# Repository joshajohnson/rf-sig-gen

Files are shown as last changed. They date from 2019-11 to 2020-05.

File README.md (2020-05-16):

# RF Signal Generator

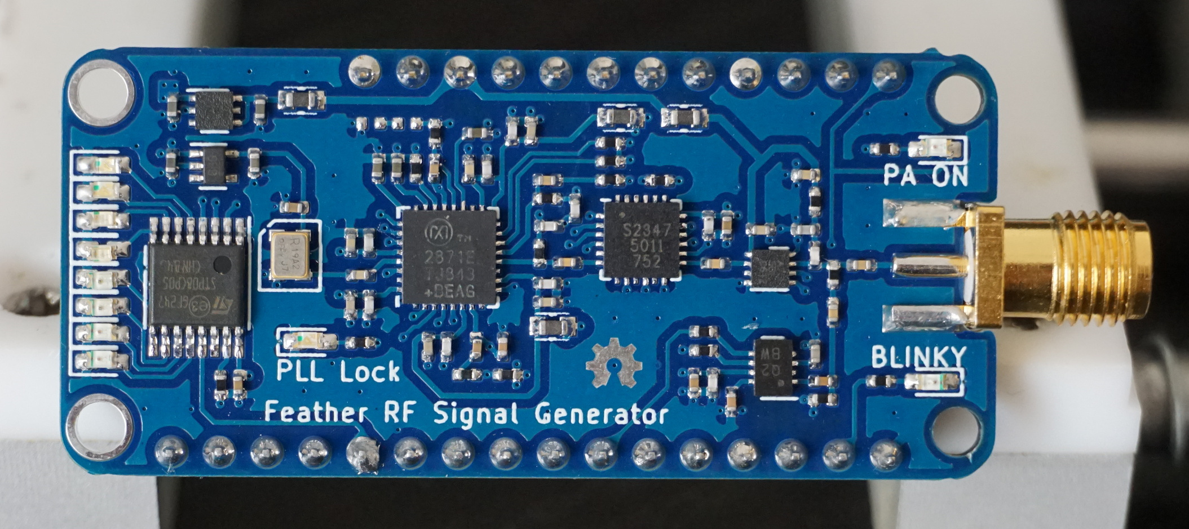
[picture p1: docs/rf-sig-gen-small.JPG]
Signal Generator


## 23.5 - 6000 MHz MAX2871 based RF signal generator in an Adafruit Feather form factor.
- MAX2871 23.5 - 6000 MHz Fractional/Integer-N Synthesizer/VCO
- -35 to +15 dBm output power (-25 to +10 across entire frequency range)
- Output control within 0.5 dB, with closed loop feedback
- GUI allowing easy control, including sweep capabilities
- Adafruit Feather form factor
- Firmware works with my [STM32F103 Feather](https://github.com/joshajohnson/stm32f103-feather)

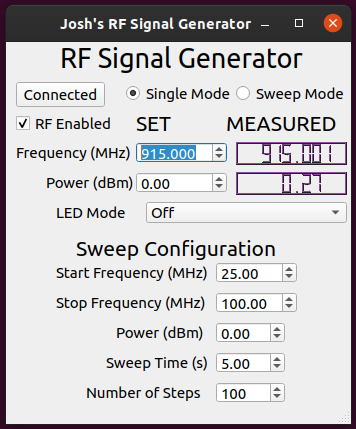
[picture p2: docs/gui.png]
GUI

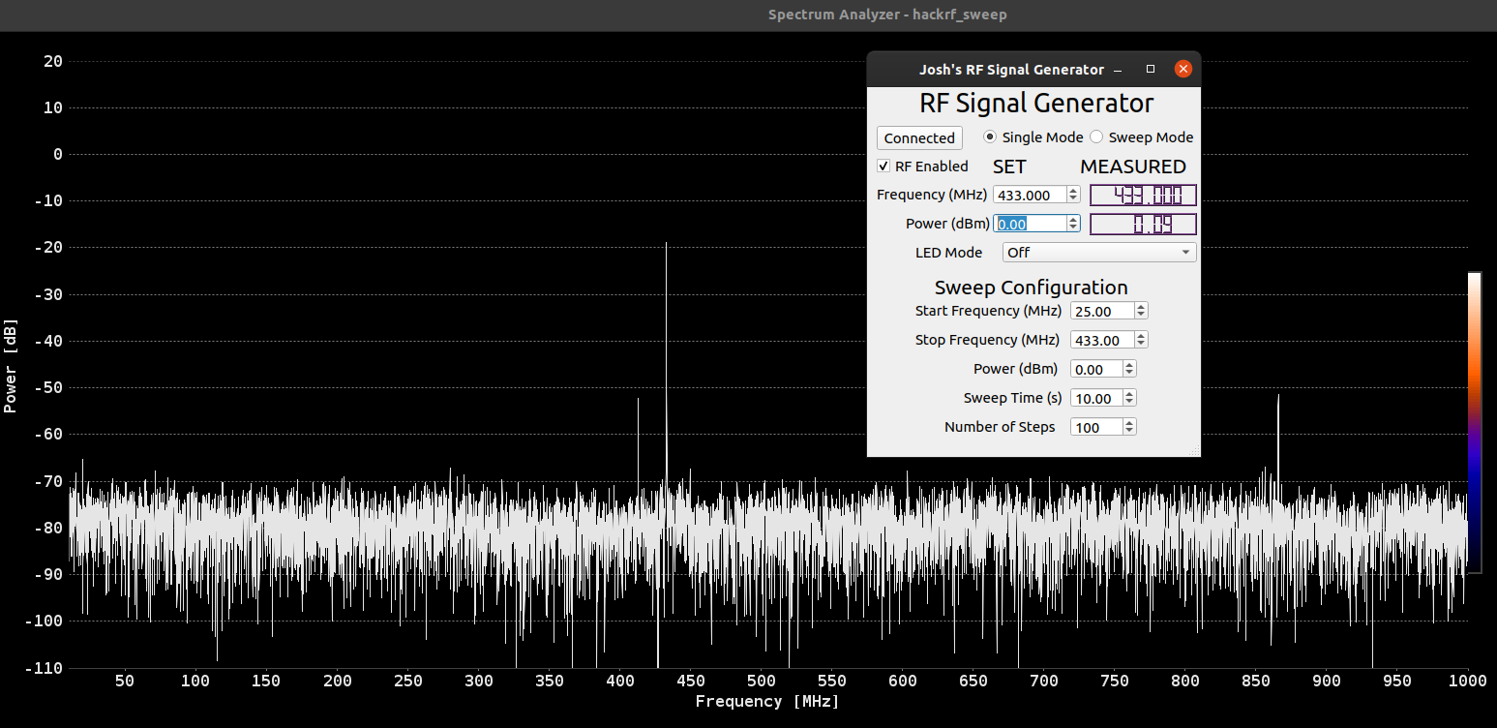
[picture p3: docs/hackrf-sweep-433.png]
GUI with hackrf_sweep spectrum view


### TODO

#### Software
- [ ] Display not updating if time between frequency steps in sweep is too long (greater than UART timeout)
- [ ] Map keyboard to frequency and power adjustment in GUI
- [ ] CLI and GUI modes based on sys.argv **NOTE CLI works but is very finiky wrt command order and updating**
- [ ] Fractional vs Int N selection

#### Firmware
- [ ] Calibrate output power
- [ ] Rewrite with RTOS to ensure a more responsive user experience
- [ ] Add ability to select Frac / Int N PLL settings
- [ ] Dimmable LEDs

#### Hardware
- [ ] Many pin locations incorrect (SPI pins off by one...)
- [ ] LED's back to front, and connected to GND instead of VCC
- [ ] Feather footprint internal pin numbers incorrect

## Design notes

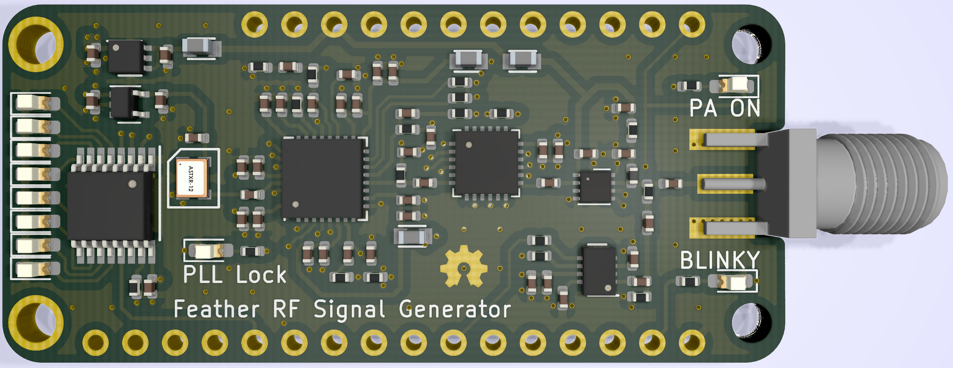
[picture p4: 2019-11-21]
docs/siggen-render.PNG

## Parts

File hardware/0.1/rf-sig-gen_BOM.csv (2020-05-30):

Qty | Reference(s) | Value | Footprint | MPN | DigiKey | LCSC | Manufacturer | DNP | Notes
5 | C1, C23, C27, C41, C43 | 100n | Capacitor_SMD:C_0402_1005Metric
9 | C10, C12, C15, C17, C31, C35, C5, C6, C8 | 10n | Capacitor_SMD:C_0402_1005Metric
10 | C11, C13, C16, C18, C20, C28, C34, C42, C7, C9 | 100p | Capacitor_SMD:C_0402_1005Metric
7 | C14, C19, C2, C21, C25, C3, C4 | 1u | Capacitor_SMD:C_0402_1005Metric
5 | C22, C30, C37, C39, C40 | 1n | Capacitor_SMD:C_0402_1005Metric
1 | C24 | 12n | Capacitor_SMD:C_0402_1005Metric
1 | C26 | DNP | Capacitor_SMD:C_0402_1005Metric
1 | C29 | 820p | Capacitor_SMD:C_0402_1005Metric
1 | C32 | 8p2 | Capacitor_SMD:C_0402_1005Metric
2 | C33, C38 | 47n | Capacitor_SMD:C_0402_1005Metric
1 | C36 | 10p | Capacitor_SMD:C_0402_1005Metric
11 | D1, D10, D11, D2, D3, D4, D5, D6, D7, D8, D9 | LED | LED_SMD:LED_0603_1608Metric_Castellated
4 | FB1, FB2, FB3, FB4 | 600R | josh-passives-smt:Ferrite_Bead_0603
1 | J1 | Feather | josh-connectors:featherwing-short
1 | J2 | SMA | josh-connectors:SMA_EDGE_MOUNT_INSET
1 | L1 | 100n | Inductor_SMD:L_0402_1005Metric
1 | R1 | 5K1 | Resistor_SMD:R_0402_1005Metric
4 | R10, R16, R19, R9 | 1K | Resistor_SMD:R_0402_1005Metric
1 | R11 | 18K | Resistor_SMD:R_0402_1005Metric
1 | R12 | 52R3 | Resistor_SMD:R_0402_1005Metric
3 | R13, R17, R4 | 49R9 | Resistor_SMD:R_0402_1005Metric
1 | R14 | 500R | Resistor_SMD:R_0402_1005Metric
1 | R15 | 1R8 | Resistor_SMD:R_0402_1005Metric
1 | R18 | 10K | Resistor_SMD:R_0402_1005Metric
2 | R2, R3 | 0R0 | Resistor_SMD:R_0402_1005Metric
1 | R20 | 2K2 | Resistor_SMD:R_0402_1005Metric
1 | R5 | 90R9 | Resistor_SMD:R_0402_1005Metric
1 | R6 | 31R1 | Resistor_SMD:R_0402_1005Metric
1 | R7 | DNP | Resistor_SMD:R_0402_1005Metric
1 | R8 | 240R | Resistor_SMD:R_0402_1005Metric
1 | U1 | MAX2871 | josh-dfn-qfn:QFN-32-1EP_5x5mm_Pitch0.5mm_Thermal_Vias
1 | U2 | LP5912 | Package_DFN_QFN:DFN-6-1EP_2x2mm_P0.65mm_EP1x1.6mm
1 | U3 | MIC5366-1.8 | Package_TO_SOT_SMD:SOT-353_SC-70-5
1 | U4 | SKY12347-362LF | Package_DFN_QFN:QFN-24-1EP_4x4mm_P0.5mm_EP2.7x2.7mm_ThermalVias
1 | U5 | TRF37A75 | Package_DFN_QFN:DFN-8-1EP_2x2mm_P0.5mm_EP0.9x1.5mm
1 | U6 | AD8319 | Package_DFN_QFN:DFN-8-1EP_2x3mm_P0.5mm_EP0.61x2.2mm
1 | U7 | STP08CP05 | Package_SO:TSSOP-16_4.4x5mm_P0.65mm
1 | XO1 | ASTXR-12-19.200MHz | josh-oscillators:ASTXR-12

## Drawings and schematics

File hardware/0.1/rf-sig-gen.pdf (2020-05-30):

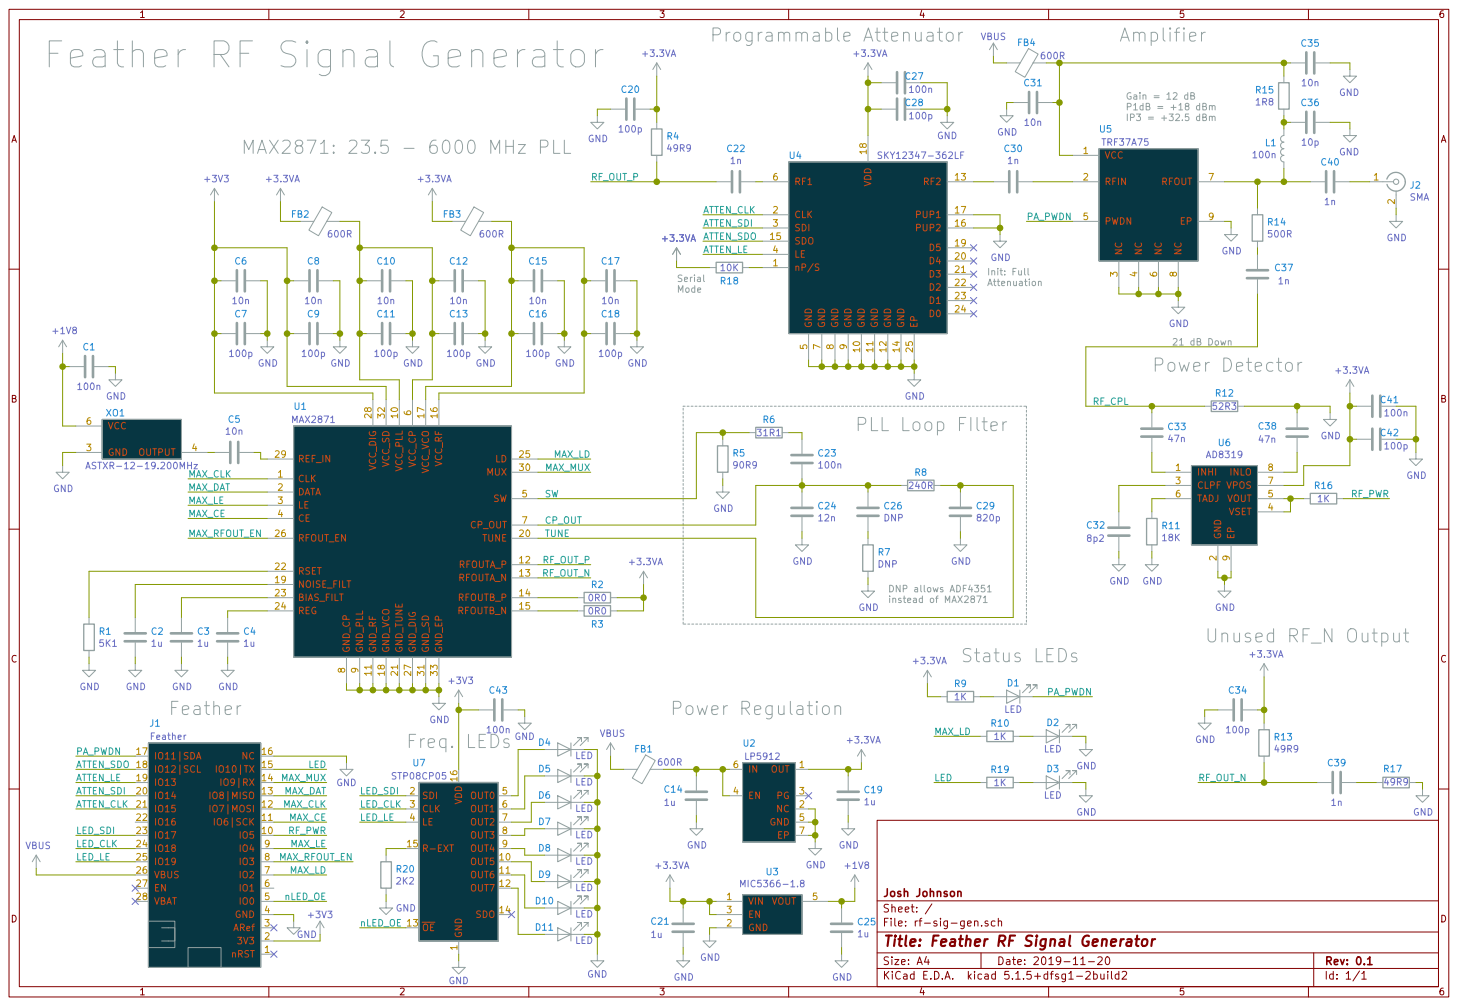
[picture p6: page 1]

9 GND 11 GND 12 RF2 13 GND 14 SDO 15 PUP1 17 D5 19 CLK 2 D4 20 D3 21 D2 22 D1 23 D0 24 SDI 3

Init: Full Attenuation PLL Loop FIlter

21 dB Down Power Detector

2 CLPF 3 VSET 4 VOUT 5 TADJ 6 VPOS 7

File: rf-sig-gen.sch Sheet: / Josh Johnson R3

1 OUT5 10 OUT6 11 OUT7 12 OE 13 SDO 14 R-EXT 15 VDD 16 SDI 2 CLK 3

Id: 1/1 Title: Feather RF Signal Generator

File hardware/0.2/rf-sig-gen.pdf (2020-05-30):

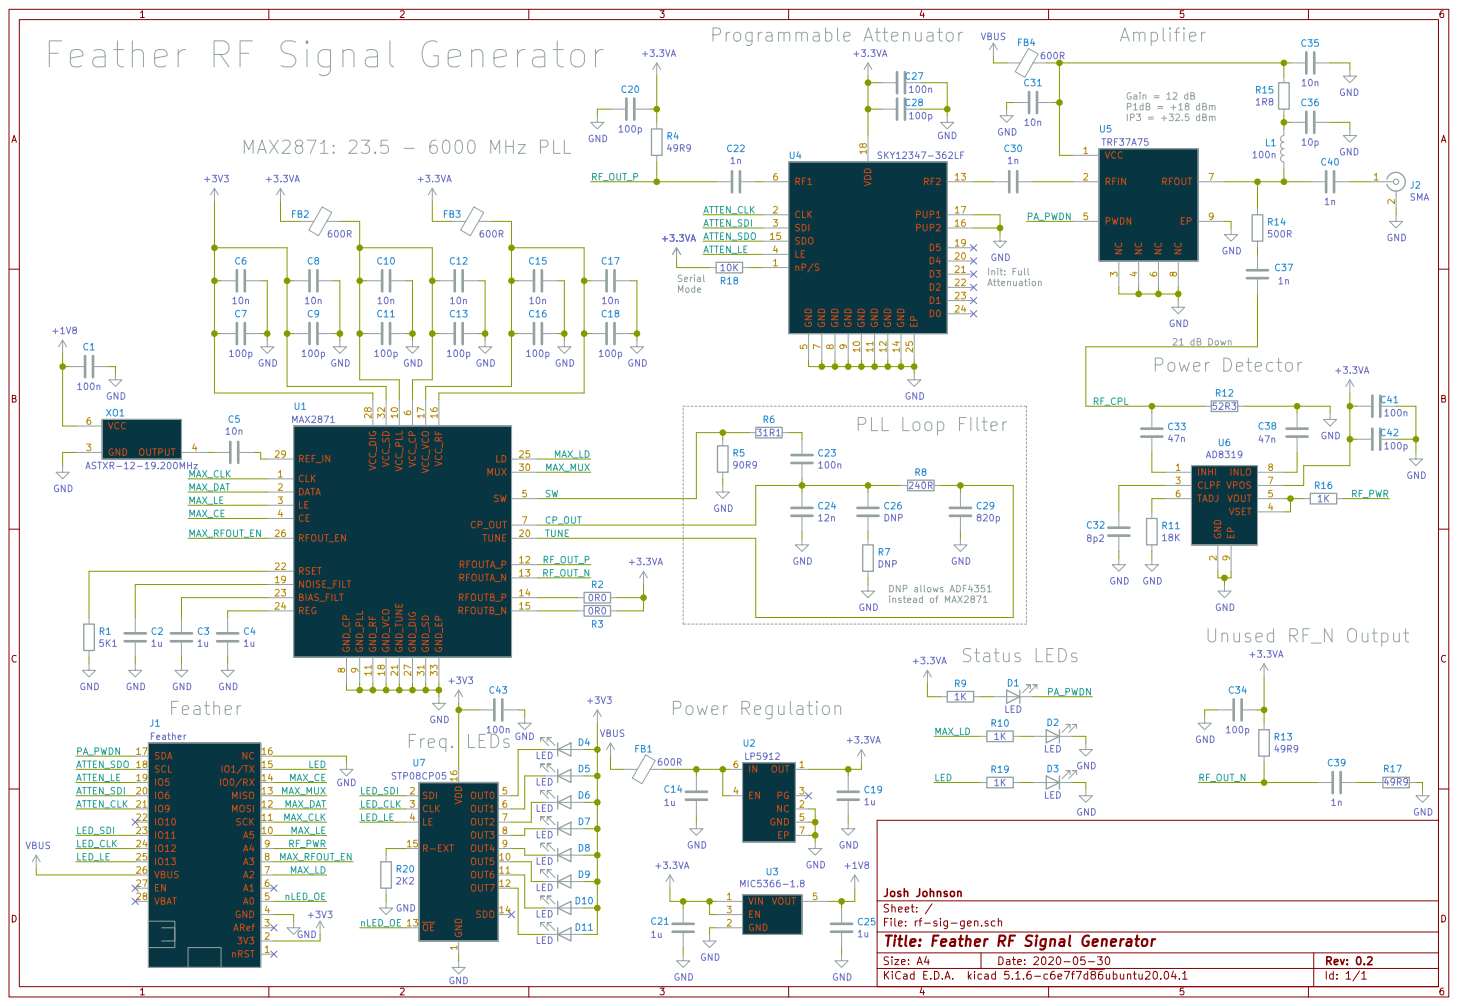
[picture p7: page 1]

21 dB Down Feather RF Signal Generator

Init: Full Attenuation MAX2871: 23.5 - 6000 MHz PLL

9 GND 11 GND 12 RF2 13 GND 14 SDO 15 PUP1 17 D5 19 CLK 2 D4 20 D3 21 D2 22 D1 23 D0 24 SDI 3
100p GND

instead of MAX2871 PLL Loop FIlter

2 CLPF 3 VSET 4 VOUT 5 TADJ 6 VPOS 7

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

Id: 1/1 Title: Feather RF Signal Generator

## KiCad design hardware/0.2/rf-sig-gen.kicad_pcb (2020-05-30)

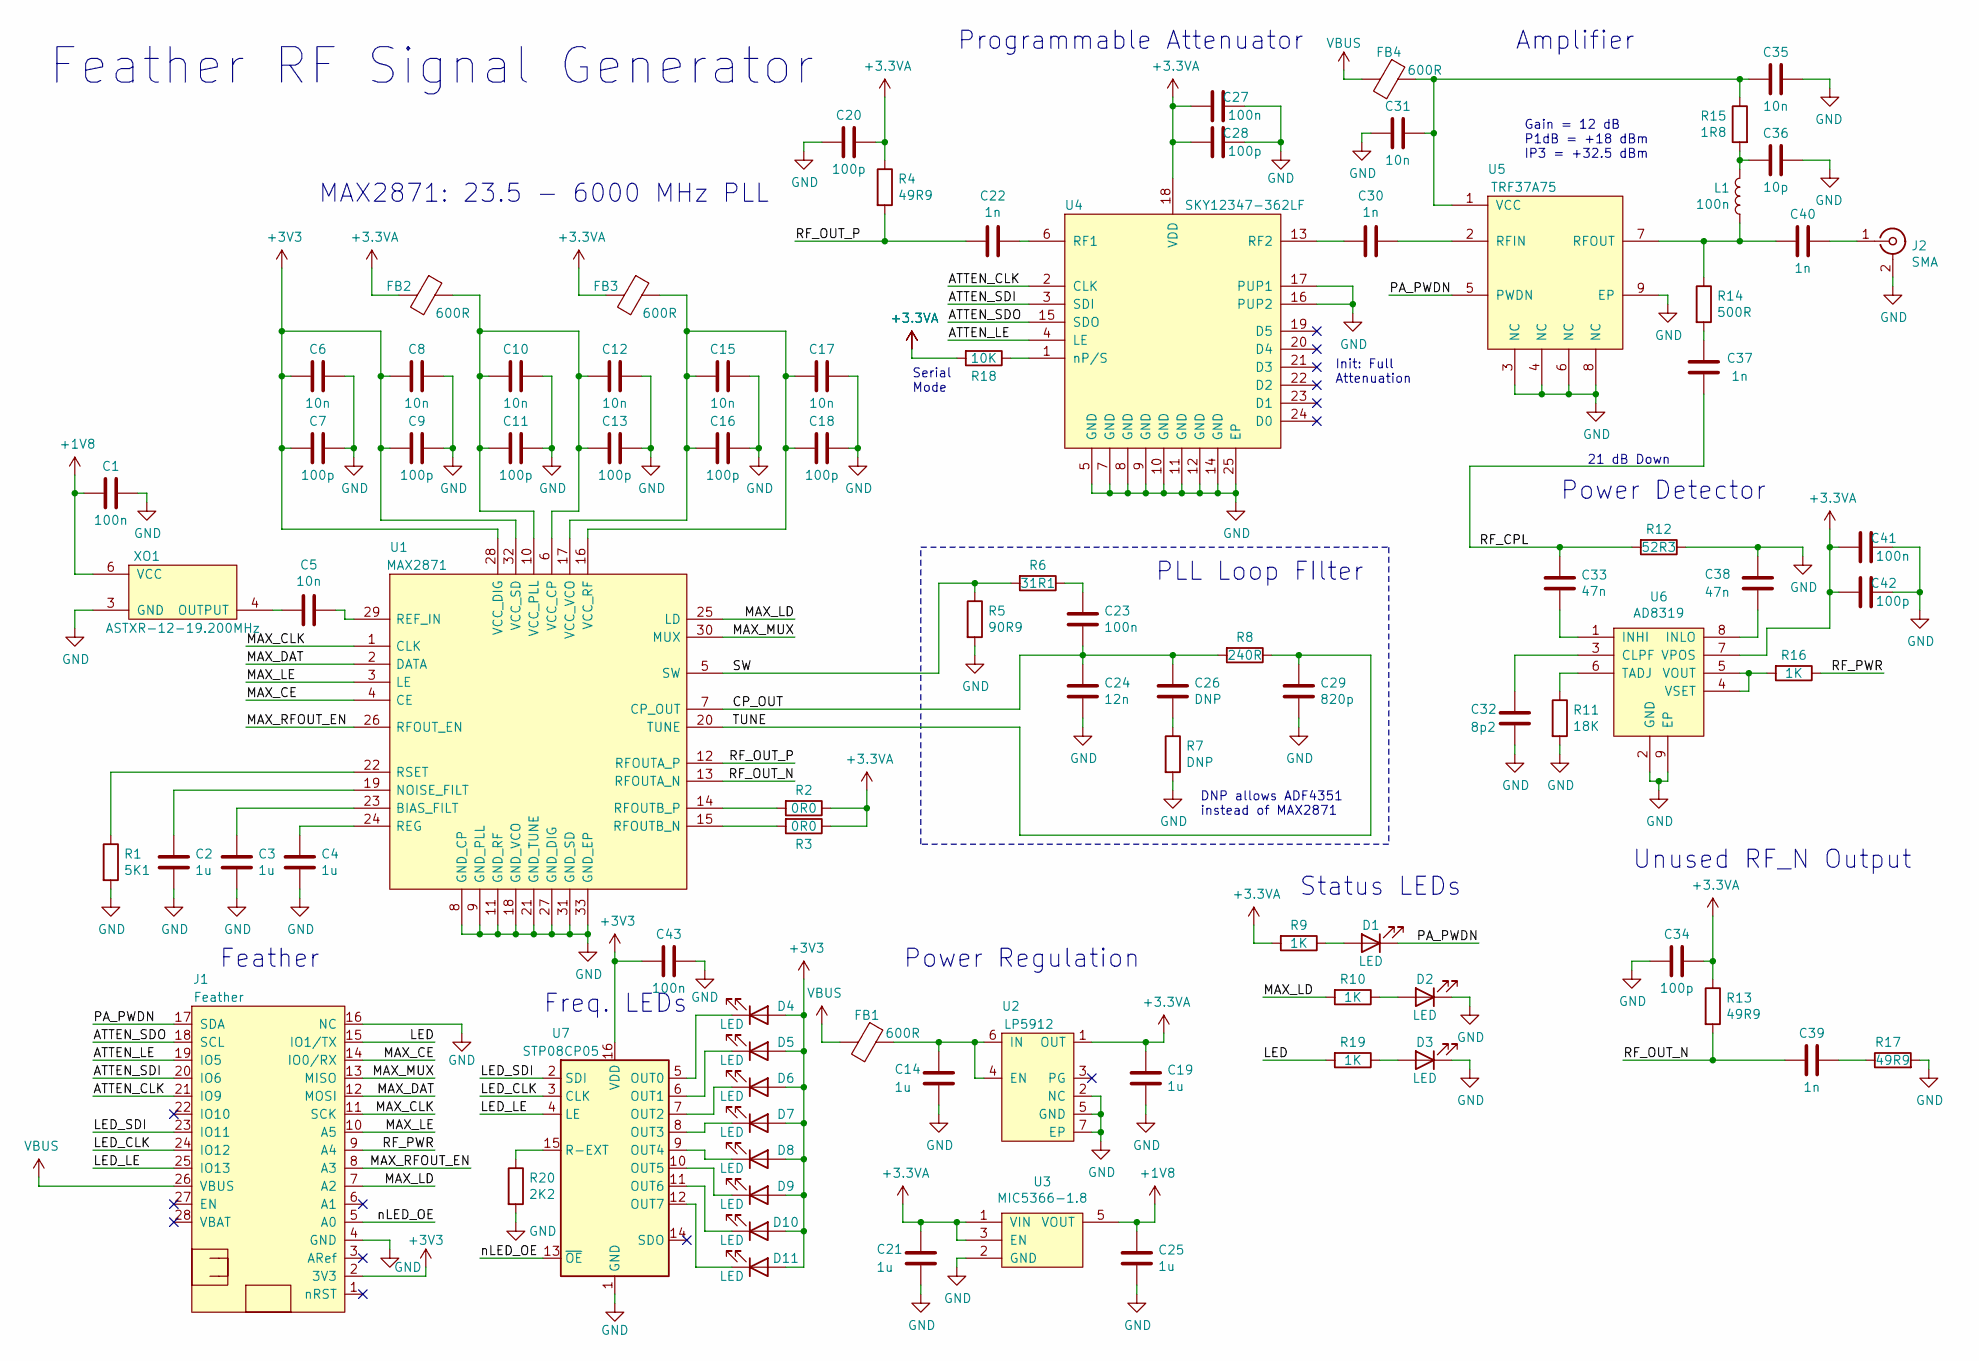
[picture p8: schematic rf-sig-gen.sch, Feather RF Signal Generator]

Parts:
C1, C23, C27, C41, C43: 100n; C_0402_1005Metric
C2, C3, C4, C14, C19, C21, C25: 1u; C_0402_1005Metric
C5, C6, C8, C10, C12, C15, C17, C31, C35: 10n; C_0402_1005Metric
C7, C9, C11, C13, C16, C18, C20, C28, C34, C42: 100p; C_0402_1005Metric
C22, C30, C37, C39, C40: 1n; C_0402_1005Metric
C24: 12n; C_0402_1005Metric
C26: DNP; C_0402_1005Metric
C29: 820p; C_0402_1005Metric
C32: 8p2; C_0402_1005Metric
C33, C38: 47n; C_0402_1005Metric
C36: 10p; C_0402_1005Metric
D1, D2, D3, D4, D5, D6, D7, D8, D9, D10, D11: LED; LED_0603_1608Metric_Castellated
FB1, FB2, FB3, FB4: 600R; Ferrite_Bead_0603
J1: Feather; featherwing-short
J2: SMA; SMA_EDGE_MOUNT_INSET
L1: 100n; L_0402_1005Metric
R1: 5K1; R_0402_1005Metric
R2, R3: 0R0; R_0402_1005Metric
R4, R13, R17: 49R9; R_0402_1005Metric
R5: 90R9; R_0402_1005Metric
R6: 31R1; R_0402_1005Metric
R7: DNP; R_0402_1005Metric
R8: 240R; R_0402_1005Metric
R9, R10, R16, R19: 1K; R_0402_1005Metric
R11: 18K; R_0402_1005Metric
R12: 52R3; R_0402_1005Metric
R14: 500R; R_0402_1005Metric
R15: 1R8; R_0402_1005Metric
R18: 10K; R_0402_1005Metric
R20: 2K2; R_0402_1005Metric
U1: MAX2871; QFN-32-1EP_5x5mm_Pitch0.5mm_Thermal_Vias; DigiKey MAX2871ETJ+TCT-ND
U2: LP5912; DFN-6-1EP_2x2mm_P0.65mm_EP1x1.6mm; DigiKey 296-44294-1-ND
U3: MIC5366-1.8; SOT-353_SC-70-5; DigiKey 576-3203-1-ND
U4: SKY12347-362LF; QFN-24-1EP_4x4mm_P0.5mm_EP2.7x2.7mm_ThermalVias; DigiKey 863-1298-1-ND
U5: TRF37A75; DFN-8-1EP_2x2mm_P0.5mm_EP0.9x1.5mm; DigiKey 296-37886-1-ND
U6: AD8319; DFN-8-1EP_2x3mm_P0.5mm_EP0.61x2.2mm; DigiKey AD8319ACPZ-R7CT-ND
U7: STP08CP05; TSSOP-16_4.4x5mm_P0.65mm; DigiKey 497-6269-1-ND
XO1: ASTXR-12-19.200MHz; ASTXR-12; DigiKey 535-12687-1-ND

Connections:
+1V8: C1.2, C25.1, U3.5 (VOUT), XO1.6 (VCC)
+3.3VA: C19.1, C20.1, C21.1, C27.2, C28.2, C34.1, C41.2, C42.2, FB2.2, FB3.2, R2.1, R3.1, R4.1, R9.2, R13.1, R18.2, U2.1 (OUT), U3.1 (VIN), U3.3 (EN), U4.18 (VDD), U6.7 (VPOS)
+3V3: C6.2, C7.2, C8.2, C9.2, C43.2, D4.2 (A), D5.2 (A), D6.2 (A), D7.2 (A), D8.2 (A), D9.2 (A), D10.2 (A), D11.2 (A), J1.2 (3V3), U1.28 (VCC_DIG), U1.32 (VCC_SD), U7.16 (VDD)
/ATTEN_CLK: J1.21 (IO9), U4.2 (CLK)
/ATTEN_LE: J1.19 (IO5), U4.4 (LE)
/ATTEN_SDI: J1.20 (IO6), U4.3 (SDI)
/ATTEN_SDO: J1.18 (SCL), U4.15 (SDO)
/CP_OUT: C23.2, C24.1, C26.1, R8.2, U1.7 (CP_OUT)
/LED: J1.15 (IO1/TX), R19.2
/LED_CLK: J1.24 (IO12), U7.3 (CLK)
/LED_LE: J1.25 (IO13), U7.4 (LE)
/LED_SDI: J1.23 (IO11), U7.2 (SDI)
/MAX_CE: J1.14 (IO0/RX), U1.4 (CE)
/MAX_CLK: J1.11 (SCK), U1.1 (CLK)
/MAX_DAT: J1.12 (MOSI), U1.2 (DATA)
/MAX_LD: J1.7 (A2), R10.2, U1.25 (LD)
/MAX_LE: J1.10 (A5), U1.3 (LE)
/MAX_MUX: J1.13 (MISO), U1.30 (MUX)
/MAX_RFOUT_EN: J1.8 (A3), U1.26 (RFOUT_EN)
/PA_PWDN: D1.1 (K), J1.17 (SDA), U5.5 (PWDN)
/RF_CPL: C33.1, C37.2, R12.2
/RF_OUT_N: C39.2, R13.2, U1.13 (RFOUTA_N)
/RF_OUT_P: C22.2, R4.2, U1.12 (RFOUTA_P)
/RF_PWR: J1.9 (A4), R16.1
/SW: R5.1, R6.2, U1.5 (SW)
/TUNE: C29.1, R8.1, U1.20 (TUNE)
/nLED_OE: J1.5 (A0), U7.13 (~OE)
GND: C1.1, C2.2, C3.2, C4.2, C6.1, C7.1, C8.1, C9.1, C10.1, C11.1, C12.1, C13.1, C14.2, C15.1, C16.1, C17.1, C18.1, C19.2, C20.2, C21.2, C24.2, C25.2, C27.1, C28.1, C29.2, C31.2, C32.2, C34.2, C35.2, C36.2, C38.1, C41.1, C42.1, C43.1, D2.1 (K), D3.1 (K), J1.4 (GND), J1.16 (NC), J2.2 (Ext), R1.2, R5.2, R7.2, R11.2, R12.1, R17.2, R20.2, U1.8 (GND_CP), U1.9 (GND_PLL), U1.11 (GND_RF), U1.18 (GND_VCO), U1.21 (GND_TUNE), U1.27 (GND_DIG), U1.31 (GND_SD), U1.33 (GND_EP), U2.2 (NC), U2.5 (GND), U2.7 (EP), U3.2 (GND), U4.5 (GND), U4.7 (GND), U4.8 (GND), U4.9 (GND), U4.10 (GND), U4.11 (GND), U4.12 (GND), U4.14 (GND), U4.16 (PUP2), U4.17 (PUP1), U4.25 (EP), U5.3 (NC), U5.4 (NC), U5.6 (NC), U5.8 (NC), U5.9 (EP), U6.2 (GND), U6.9 (EP), U7.1 (GND), XO1.3 (GND)
unnamed: C2.1, U1.19 (NOISE_FILT)
unnamed: C3.1, U1.23 (BIAS_FILT)
unnamed: C4.1, U1.24 (REG)
unnamed: C5.1, U1.29 (REF_IN)
unnamed: C5.2, XO1.4 (OUTPUT)
unnamed: C10.2, C11.2, C12.2, C13.2, FB2.1, U1.6 (VCC_CP), U1.10 (VCC_PLL)
unnamed: C14.1, FB1.1, U2.4 (EN), U2.6 (IN)
unnamed: C15.2, C16.2, C17.2, C18.2, FB3.1, U1.16 (VCC_RF), U1.17 (VCC_VCO)
unnamed: C22.1, U4.6 (RF1)
unnamed: C23.1, R6.1
unnamed: C26.2, R7.1
unnamed: C30.1, U5.2 (RFIN)
unnamed: C30.2, U4.13 (RF2)
unnamed: C31.1, C35.1, FB4.1, R15.1, U5.1 (VCC)
unnamed: C32.1, U6.3 (CLPF)
unnamed: C33.2, U6.1 (INHI)
unnamed: C36.1, L1.1, R15.2
unnamed: C37.1, R14.2
unnamed: C38.2, U6.8 (INLO)
unnamed: C39.1, R17.1
unnamed: C40.1, J2.1 (In)
unnamed: C40.2, L1.2, R14.1, U5.7 (RFOUT)
unnamed: D1.2 (A), R9.1
unnamed: D2.2 (A), R10.1
unnamed: D3.2 (A), R19.1
unnamed: D4.1 (K), U7.5 (OUT0)
unnamed: D5.1 (K), U7.6 (OUT1)
unnamed: D6.1 (K), U7.7 (OUT2)
unnamed: D7.1 (K), U7.8 (OUT3)
unnamed: D8.1 (K), U7.9 (OUT4)
unnamed: D9.1 (K), U7.10 (OUT5)
unnamed: D10.1 (K), U7.11 (OUT6)
unnamed: D11.1 (K), U7.12 (OUT7)
unnamed: R1.1, U1.22 (RSET)
unnamed: R2.2, U1.14 (RFOUTB_P)
unnamed: R3.2, U1.15 (RFOUTB_N)
unnamed: R11.1, U6.6 (TADJ)
unnamed: R16.2, U6.4 (VSET), U6.5 (VOUT)
unnamed: R18.1, U4.1 (nP/S)
unnamed: R20.1, U7.15 (R-EXT)
VBUS: FB1.2, FB4.2, J1.26 (VBUS)

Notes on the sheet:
MAX2871: 23.5 - 6000 MHz PLL
PLL Loop FIlter
DNP allows ADF4351 instead of MAX2871
Unused RF_N Output
Serial Mode
Init: Full Attenuation
Programmable Attenuator
Feather RF Signal Generator
Amplifier
Gain = 12 dB P1dB = +18 dBm IP3 = +32.5 dBm
Power Detector
21 dB Down
Power Regulation
Status LEDs
Freq. LEDs
Feather

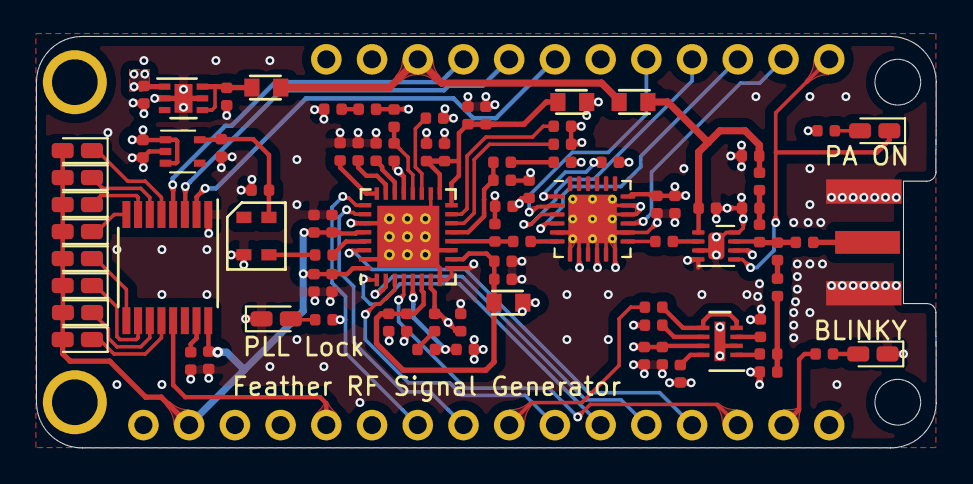
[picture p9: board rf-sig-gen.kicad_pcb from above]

Board: 4 copper layers, 50.0 x 22.9 mm, 89 parts (0 on the bottom side), 69 nets.

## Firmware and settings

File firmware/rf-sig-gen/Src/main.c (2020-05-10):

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

/* Includes ------------------------------------------------------------------*/
#include "main.h"
#include "adc.h"
#include "tim.h"
#include "usb_device.h"
#include "gpio.h"

/* USER CODE BEGIN Includes */
#include <stdio.h>
#include <string.h>
#include "usbd_cdc_if.h"
#include "dwt_stm32_delay.h"
#include "commandParser.h"
#include "max2871.h"
#include "max2871_registers.h"
#include "txChain.h"
#include "STP08CP05.h"
/* USER CODE END Includes */

/* USER CODE BEGIN PTD */
FIFO RX_FIFO = {.head = 0, .tail = 0};
/* USER CODE END PTD */


/* USER CODE BEGIN PV */

extern struct MAX2871Struct max2871Status;
extern struct txStruct txStatus;

/* USER CODE END PV */

void SystemClock_Config(void);
/* USER CODE BEGIN PFP */
void enumerateUSB(void);
/* USER CODE END PFP */

/**
  * @brief  The application entry point.
  * @retval int
  */
int main(void)
{
  

  /* MCU Configuration--------------------------------------------------------*/

  /* Reset of all peripherals, Initializes the Flash interface and the Systick. */
  HAL_Init();

  /* Configure the system clock */
  SystemClock_Config();

  /* Initialize all configured peripherals */
  MX_GPIO_Init();
  MX_ADC1_Init();
  MX_USB_DEVICE_Init();
  MX_TIM1_Init();
  /* USER CODE BEGIN 2 */
  DWT_Delay_Init();
  enumerateUSB(); // Force USB enumeration
  txChainInit(&max2871Status, &txStatus);
  HAL_ADC_Start(&hadc1);
  HAL_GPIO_WritePin(LED_CLK_GPIO_Port, LED_CLK_Pin, 0); //  LED Control

  /* USER CODE END 2 */

  /* Infinite loop */
  /* USER CODE BEGIN WHILE */
  while (1)
  {
    // Wait for a command
	  if (RX_FIFO.dataReady == 1)
	  {
		  commandParser(&max2871Status, &txStatus);
	  }
    /* USER CODE END WHILE */

    /* USER CODE BEGIN 3 */
  }
  /* USER CODE END 3 */
}

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
/* USER CODE BEGIN 4 */
void enumerateUSB(void){
  GPIO_InitTypeDef GPIO_InitStruct = {0};

  GPIO_InitStruct.Pin = USB_PU_Pin;
  GPIO_InitStruct.Mode = GPIO_MODE_OUTPUT_PP;
  GPIO_InitStruct.Pull = GPIO_NOPULL;
  GPIO_InitStruct.Speed = GPIO_SPEED_FREQ_LOW;
  HAL_GPIO_Init(GPIOA, &GPIO_InitStruct);
  HAL_GPIO_WritePin(USB_PU_GPIO_Port, USB_PU_Pin, 0);

  HAL_Delay(500);

  GPIO_InitStruct.Pin = USB_PU_Pin;
  GPIO_InitStruct.Mode = GPIO_MODE_INPUT;
  GPIO_InitStruct.Pull = GPIO_NOPULL;
  HAL_GPIO_Init(GPIOA, &GPIO_InitStruct);
}
/* USER CODE END 4 */
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


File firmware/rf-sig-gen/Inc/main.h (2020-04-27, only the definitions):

#define FRAC_N 		0
#define INT_N		1
#define nVERBOSE 	0
#define VERBOSE 	1
#define MAX_LE_Pin GPIO_PIN_1
#define MAX_LE_GPIO_Port GPIOA
#define MAX_RFOUT_EN_Pin GPIO_PIN_2
#define MAX_RFOUT_EN_GPIO_Port GPIOA
#define MAX_LD_Pin GPIO_PIN_3
#define MAX_LD_GPIO_Port GPIOA
#define nLED_OE_Pin GPIO_PIN_5
#define nLED_OE_GPIO_Port GPIOA
#define ATTEN_LE_Pin GPIO_PIN_6
#define ATTEN_LE_GPIO_Port GPIOA
#define ATTEN_SDO_Pin GPIO_PIN_7
#define ATTEN_SDO_GPIO_Port GPIOA
#define ATTEN_CLK_Pin GPIO_PIN_0
#define ATTEN_CLK_GPIO_Port GPIOB
#define LED_SDI_Pin GPIO_PIN_10
#define LED_SDI_GPIO_Port GPIOB
#define LED_CLK_Pin GPIO_PIN_11
#define LED_CLK_GPIO_Port GPIOB
#define LED_LE_Pin GPIO_PIN_12
#define LED_LE_GPIO_Port GPIOB
#define nLED_RED_Pin GPIO_PIN_13
#define nLED_RED_GPIO_Port GPIOB
#define nLED_GRN_Pin GPIO_PIN_14
#define nLED_GRN_GPIO_Port GPIOB
#define nLED_BLU_Pin GPIO_PIN_15
#define nLED_BLU_GPIO_Port GPIOB
#define nLED_USR_Pin GPIO_PIN_8
#define nLED_USR_GPIO_Port GPIOA
#define SWDIO_Pin GPIO_PIN_13
#define SWDIO_GPIO_Port GPIOA
#define SWDCLK_Pin GPIO_PIN_14
#define SWDCLK_GPIO_Port GPIOA
#define USB_PU_Pin GPIO_PIN_15
#define USB_PU_GPIO_Port GPIOA
#define MAX_CE_Pin GPIO_PIN_3
#define MAX_CE_GPIO_Port GPIOB
#define MAX_DAT_Pin GPIO_PIN_4
#define MAX_DAT_GPIO_Port GPIOB
#define MAX_CLK_Pin GPIO_PIN_5
#define MAX_CLK_GPIO_Port GPIOB
#define LED_Pin GPIO_PIN_6
#define LED_GPIO_Port GPIOB
#define MAX_MUX_Pin GPIO_PIN_7
#define MAX_MUX_GPIO_Port GPIOB
#define ATTEN_SDI_Pin GPIO_PIN_8
#define ATTEN_SDI_GPIO_Port GPIOB
#define PA_PWDN_Pin GPIO_PIN_9
#define PA_PWDN_GPIO_Port GPIOB

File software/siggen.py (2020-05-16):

import sys
import argparse
import serial
from serial.tools import list_ports
import io
from PyQt5 import QtWidgets, uic, QtCore


class SignalGenerator:
    """ Class to handle configuration of the Signal Generator. Parses CLI args to send correct info to the SigGen. """

    def __init__(self):

        # Serial things
        self.com_port = None
        self.connected = False
        self.serial = None
        self.serial_io = None
        self.serial_recv_line = None
        self.serial_user_data = []

        # Argparse
        self.parser = None
        self.user_input = []
        self.args = None

        # Command line args
        self.mode = "generator"
        self.frequency = 25
        self.power = 0
        self.sweep_start = 25
        self.sweep_stop = 100
        self.sweep_steps = 100
        self.sweep_time = 5
        self.led_display = "kitt"
        self.rf_enabled = False
        self.updated = False
        self.siggen_init = False

    def find_serial(self):
        """ Find a Signal Generator """

        # Find which COM port it is connected to
        ports = list_ports.comports()
        if ports != []:
            for port, desc, hwid in sorted(ports):
                # print("{}: {} [{}]".format(port, desc, hwid))
                if desc == "RF Signal Generator":
                    self.com_port = port

        if self.com_port == False:
            print("Signal Generator not found!")
        else:
            print("Signal Generator found on port: {}".format(self.com_port))

    def connect_serial(self):
        """ Connect to a Signal Generator """

        sig_gen.siggen_init = False
        self.find_serial()

        try:
            self.serial = serial.Serial(self.com_port, 115200, timeout=0.2)
            self.serial_io = io.TextIOWrapper(
                io.BufferedRWPair(self.serial, self.serial))

            # #self.serial.open()
            self.serial_io.write("WHOAMI" + "\r\n")
            self.serial_io.flush()
            self.serial_recv_line = self.serial_io.readline().rstrip().lstrip("> ")

            # Confirm WHOAMI is correct
            if self.serial_recv_line == "Josh's Signal Generator!":
                print("Connected to {}".format(self.serial_recv_line))
                self.connected = True
        except:
            print("Could not connect.")

    def connect(self):
        """ Finds and Connects to Signal Generator """
        self.connect_serial()

    def check_connection(self):
        """ Checks if the SigGen is connected, and attemps to connect if not. """

        if self.serial:
            if self.serial.is_open:
                self.serial.close()

        try:
            if self.connected:
                self.serial_io.write("WHOAMI" + "\r\n")
                self.serial_io.flush()
                ret_val = self.serial_io.readline().rstrip().lstrip("> ")
                if ret_val == "Josh's Signal Generator!":
                    self.connected = True
        except:
            pass
        self.connect_serial()

    def send_data(self, data):
        """ Sends data to Signal Generator """
        if self.connected:
            self.serial_io.write(data + "\r\n")
            self.serial_io.flush()
            if (verbosity >= 1): 
                print(data)
        else:
            print("Connect to Device before use.")

    def get_data(self):
        """ Gets multiple lines from Signal Generator, until timeout is hit """

        if self.connected:
            global meas_freq
            global meas_power

            while (True):
                gui.processEvents()

                raw_recv = self.serial_io.readline()
                if (raw_recv == ""):
                    break

                if raw_recv[0] == ">" and verbosity >= 1:
                    print(raw_recv.rstrip())
                if raw_recv[0] == "+" and verbosity >= 3:
                    print(raw_recv.rstrip())
                if raw_recv[0] == "?":
                    # Send data for updating display
                    meas_freq = raw_recv.split(" ")[1]
                    meas_power = raw_recv.split(" ")[2]
                    if verbosity >= 2:
                        print(raw_recv.rstrip())

    def talk(self):
        """ Transparently opens a COM port between user and Signal Generator """

        if not self.connected:
            self.connect_serial()

        if self.connected:
            while True:
                user_input = input()
                if user_input.lower == "exit":
                    break
                self.send_data(user_input)
                self.get_data()
                [print(line) for line in self.serial_user_data]

    def config_sig_gen(self, frequency=None, power=None):
        """ Sets SigGen params """

        if frequency is None:
            frequency = self.frequency
        if power is None:
            power = self.power

        self.send_data("sigGen({},{})".format(frequency, power))
        self.get_data()

    def config_sweep(self, start_freq=None, stop_freq=None, power=None, sweep_steps=None, time=None):
        """ Configures sweep params."""

        if start_freq is None:
            start_freq = self.sweep_start
        if stop_freq is None:
            stop_freq = self.sweep_stop
        if power is None:
            power = self.power
        if sweep_steps is None:
            sweep_steps = self.sweep_steps
        if time is None:
            time = self.sweep_time

        self.send_data("sweep({},{},{},{},{})".format(
            start_freq, stop_freq, sweep_steps, power, time))
        self.get_data()

    def config_RF(self, enabled=False):
        """ Enables / Disables RF output """

        if enabled:
            self.rf_enabled = True
            self.send_data("enableRF")
            self.get_data()
        else:
            self.rf_enabled = False
            self.send_data("disableRF")
            self.get_data()

    def config_leds(self, led_display=None):
        """ Configures the all important LED patterns """

        available_displays = ["kitt", "binary", "rainbow"]

        if led_display == "off":
            self.send_data("led 0")
        else:
            if led_display in available_displays:
                self.send_data("{}".format(led_display))
            else:
                print("LED option not found.")

    def parse_inputs(self, user_input):
        """ Parses inputs to the Signal Generator """

        self.parser = argparse.ArgumentParser(
            description="Controls RF Signal Generator")
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

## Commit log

2019-11-20 add KiCad files
    [rf-sig-gen.kicad_pcb, rf-sig-gen.sch]
2019-11-21 update schematic
    [rf-sig-gen.kicad_pcb, rf-sig-gen.sch]
2019-12-17 more progress
    [rf-sig-gen.kicad_pcb]
2019-12-18 final changes
    [rf-sig-gen.kicad_pcb]
2020-04-27 move to correct repo
    [STP08CP05.c]
2020-05-09 bug squashing and improvment for gui
    [STP08CP05.c, max2871.c, txChain.c]
2020-05-16 adding features / bug hunting
    [siggen.py]

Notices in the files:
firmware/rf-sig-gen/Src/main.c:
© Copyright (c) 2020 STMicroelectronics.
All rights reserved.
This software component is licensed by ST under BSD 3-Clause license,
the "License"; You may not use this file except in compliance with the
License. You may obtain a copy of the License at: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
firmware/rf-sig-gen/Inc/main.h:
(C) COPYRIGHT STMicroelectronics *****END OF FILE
